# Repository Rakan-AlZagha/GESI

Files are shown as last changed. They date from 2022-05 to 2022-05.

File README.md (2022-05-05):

# Gesture-Enabled System Interaction (GESI) 

Wide

## Introduction
This project was created as part of the Department of Computer Science, Trinity College (Hartford, CT), Senior Capstone project. I was advised by Dr. Maminur Islam both semesters. 

You will find all files: training and testing scripts, 3D STL designs, presentation and poster, and the code for the ESP-EYE live stream here.

## Abstract
Gesture Enabled System Interaction (GESI) is a project that enables users to interact effectively
with devices based on intuitive hand gestures. 

With the exception of gaming, touch and voice have dominated the way we interact with technology over the last decade. Enabling users to utilize gestures to operate and interact with appliances, speakers, lights, machines, and more
will allow us to develop more interactive and robust technology. 

The purpose of this project is to add another dimension of user interaction with various systems and technologies. To achieve
this, I am developing a wearable piece of technology using the ESP-EYE microcontroller that will be mounted to a pair of 3D-designed and printed glasses. The microcontroller will broadcast raw real-time video of a user’s hand motions (first-person view) which will be intercepted by the object-detection algorithm running remotely. 

Once a gesture is recognized by the deep-learning object detection model, an API request will be sent to Amazon’s Alexa API (referred to as “skills”) for direct device interaction. A user will be able to interact with any device connected to
their Alexa account by issuing gestures that are unique to that specific device. 

As the project progresses, ultimately, the end-product will be optimized for reliable, robust, and natural
interactions with connected technologies.

## Current Work
Looking at current day approaches to gesture-based technology, the work is split between IoT developers and some commercial products. A company named Fibaro designs smart home devices/applications and has recently developed a gesture-based technology called “Swipe”. The idea behind it is to place a tablet in a common space at home and issue gestures to control home devices and music systems. The issue with this design is the lack of movability and robustness. Users need to be in a certain place in their house and within a certain range of proximity in order to operate these devices. It is not practical for user stories that would involve being able to operate devices via gestures from multiple locations. 

Other designs include hand-tracking via accelerometers, using a Xbox Kinect as a tracker, or using a wearable watch that records gestures. These designs are bulky, lack mobility, and do not directly address the need for gesture-control to be natural and robust. There is one project, named SHAIDES by Nick Bild, a software engineer, that begins to address the issues above. He utilizes one dynamic gesture to turn on and off a light using a bulky Jetson Nano and a Raspberry Pi Camera (later switches to a microcontroller for more lightweight use). He accomplishes interfacing with one API (Phillips REST), but this is the extent that his project went to and lacks integration to a broader range of devices and user autonomy over gestures. 

Taking all of this into consideration, I aim to follow the effective design choices of previous work and avoid previous mistakes that resulted in failures. This project will focus on usability, mobility (in terms of being able to utilize it from multiple locations), and integrating a user-friendly and natural interface. I will be taking the core ideas expressed by the aforementioned researchers and IoT projects and extending it to a unique model that incorporates the most effective hardware and software choices. My design will be unique to previous approaches by allowing for users to interface with multiple devices based on defined gestures (static/dynamic), integrate a lightweight sleek wearable solution, and cover a broad range of functionality (across types of devices). 

## Significance
With the emergence of platforms such as Amazon Alexa and Google Home that allow you to connect smart devices to one platform, the relevance of this project is vast. The best way to encapsulate the significance of this project is to provide a scenario. 

Imagine you, a proud owner of this product (GESI), are coming home from work and with the gesture of your hand you can open your car garage. Right when you enter the house, you decide to turn on the lights with another gesture. Say you are feeling cold on a cold fall evening, with one gesture you can control your thermostat without the click of a button. Music? Pre-programmable gestures to access your favorite playlists and automatically play on your bluetooth speaker via Alexa. Bedtime? One gesture to power off your room lights, close your motorized curtains, and turn off your TV with a specified night mode gesture-motion. The possibilities are simply endless. This product would enable users to access another dimension of user-interaction with systems. 

## Methodology 
### Diagram of technical process
final-diag

MediaPipe Hands is a high-fidelity hand and finger tracking solution. It employs machine learning (ML) to infer 21 3D landmarks of a hand from just a single frame. It is used here to extract the most important nodes on the palm and fingers to train the gesture-recognition algorithm and later test the unknown gestures coming from the user. 

VoiceMonkey allows you to trigger Alexa routines externally from services such as IFTTT and Home Assistant and offers dynamic text-to-speech (TTS) capabilities. Essentially, we can use Alexa without speaking. It is as simple as creating a "Monkey", creating an Alexa routine to pair the monkey with Alexa's functionality, and then triggering it from the testing script (pair gesture to command).

For more information regarding MediaPipe and VoiceMonkey:
https://google.github.io/mediapipe/solutions/hands.html

https://voicemonkey.io/

## Final Product
### Glasses



### Glasses with battery and ESP-EYE mounted
IMG_9500 (2)

### Smart Home Mode
https://user-images.githubusercontent.com/56772433/166870876-bbc511b6-0143-480e-b7a3-64f70b14b61e.mp4

https://user-images.githubusercontent.com/56772433/166870782-8f62e7c0-6f62-45b8-8c57-db330b099c72.mp4

### Presentation Mode

https://user-images.githubusercontent.com/56772433/166870836-4533b042-be06-4260-839d-aab758ede73c.mp4

### Music Mode

https://user-images.githubusercontent.com/56772433/166870812-0328952b-4d6f-45e7-8189-26ac06d0df64.mp4

## Special considerations
Learning: 
- OpenCV course (LinkedIn Learning)
- Object-detection course
- Microcontroller and Arduino course
- General IoT course
- MediaPipe
- VoiceMonkey

### Special Equipment: 
ESP Eye Microcontroller - 
https://www.amazon.com/Espressif-ESP-Eye-Camera-Digital-Microphone/dp/B07RD7BG8L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

Powerbank for remote power - 
https://www.amazon.com/Diymore-Battery-Shield-Raspberry-Arduino/dp/B0784FPF8J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

Batteries - 
https://www.18650batterystore.com/products/samsung-25r-18650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

CAD designed glasses for microcontroller (can use local library 3D printer for free)

Budget = ~$50

## Future Directions
- Improve gesture-recognition algorithm in different conditions
- Train on different hand sizes for more accurate predictions
- Develop a user-oriented method of pairing gestures to commands via a web or iOS application
- Expanding to different smart-home interfaces (Google Home & HomePod)
- Improve comfort of glasses and make design sleeker

### Please email alzagharakan@gmail.com with any questions, ideas, or comments.

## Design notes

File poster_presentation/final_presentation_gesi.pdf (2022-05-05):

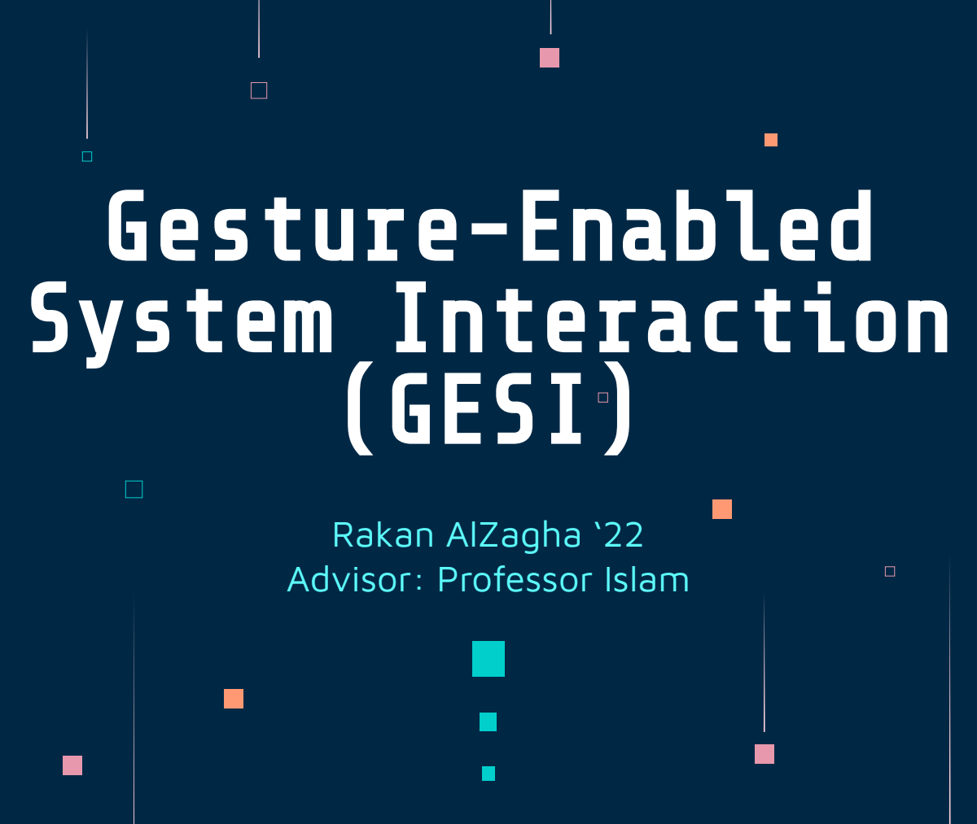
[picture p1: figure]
Rakan AlZagha ‘22 Advisor: Professor Islam; Gesture-Enabled System Interaction (GESI)

# Develop a user-friendly end product that allows users to interact effectively with devices based on intuitive hand

gestures.

# Project Goal

# Journey to Completion

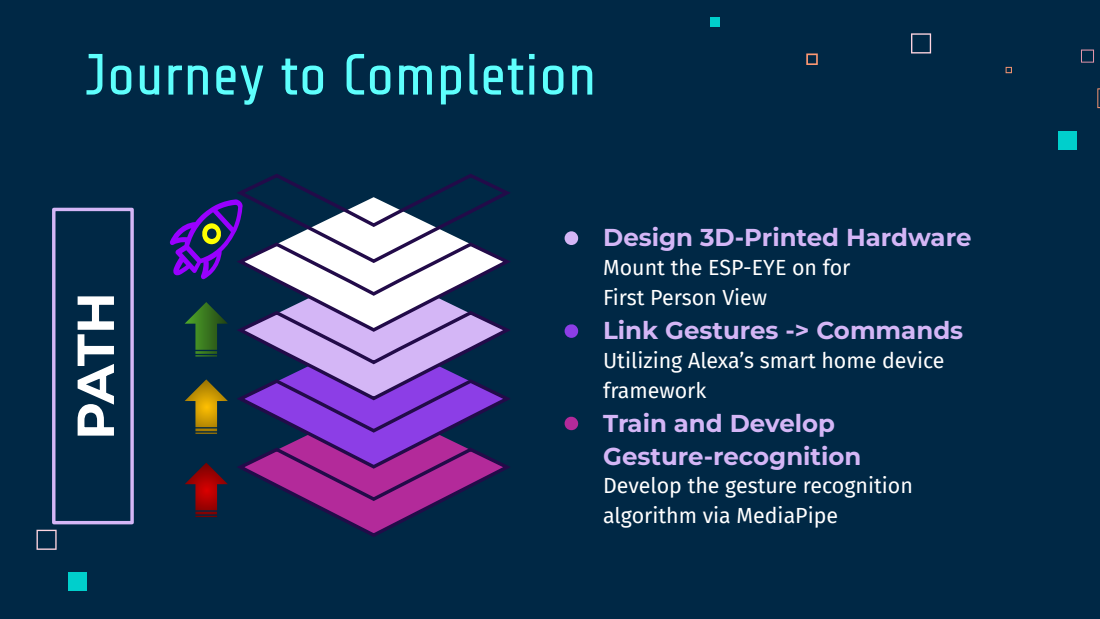
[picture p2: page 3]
PATH

Design 3D-Printed Hardware
Mount the ESP-EYE on for
First Person View
Link Gestures -> Commands
Utilizing Alexa’s smart home device
framework
Train and Develop
Gesture-recognition
Develop the gesture recognition
algorithm via MediaPipe

# Technical Specifications

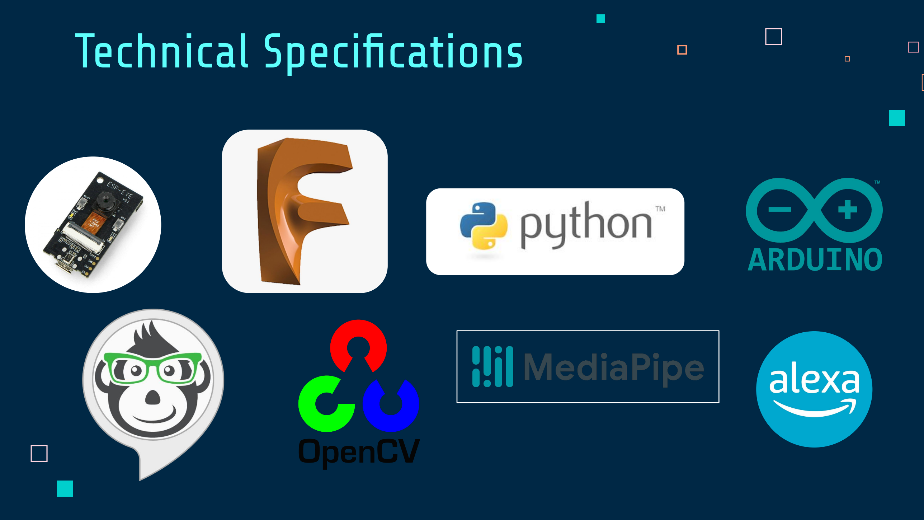
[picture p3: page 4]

# Hand-Tracking Solution

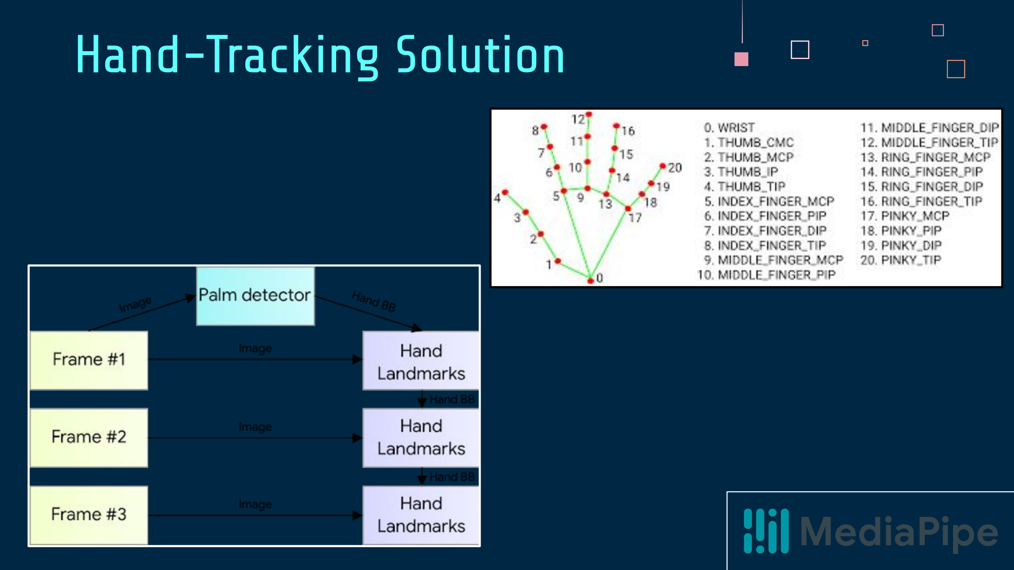
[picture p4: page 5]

# Technical Process

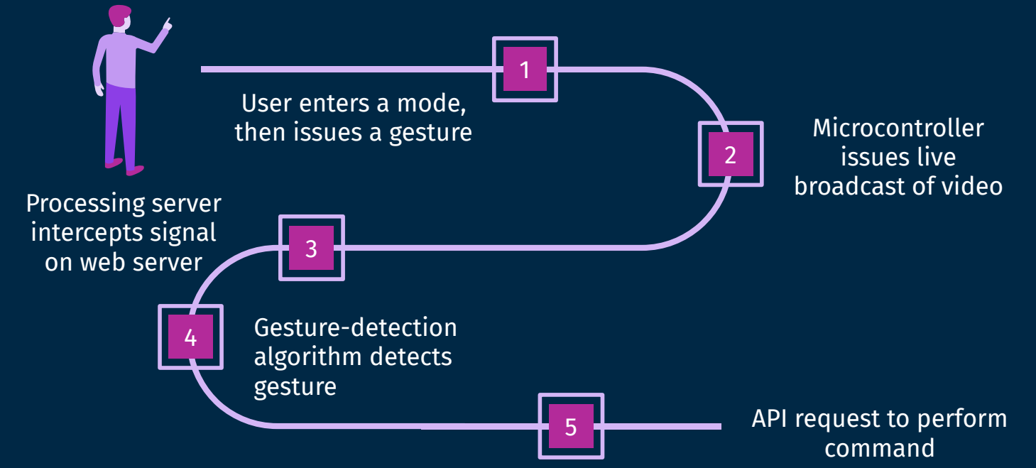
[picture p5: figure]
API request to perform; command; Processing server intercepts signal on web server; User enters a mode, then issues a gesture; Gesture-detection algorithm detects gesture; Microcontroller issues live broadcast of video

# 3D Prints

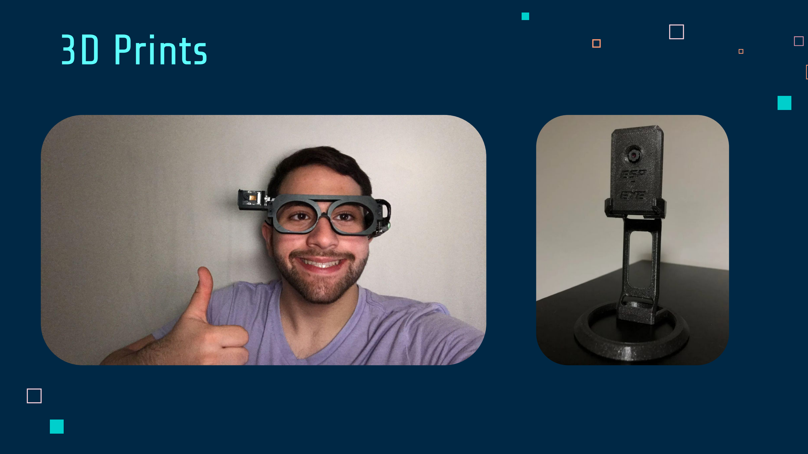
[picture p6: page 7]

# DEMO TIME

# Gesture Tracking

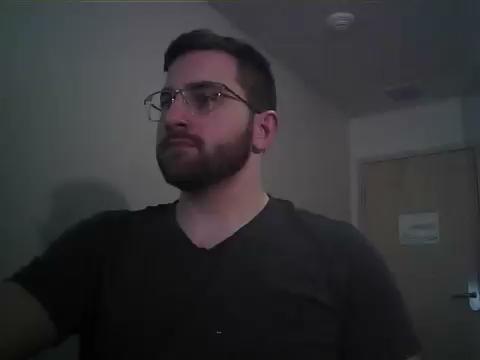
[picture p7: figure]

# Smart Home Mode

# Smart Home Mode

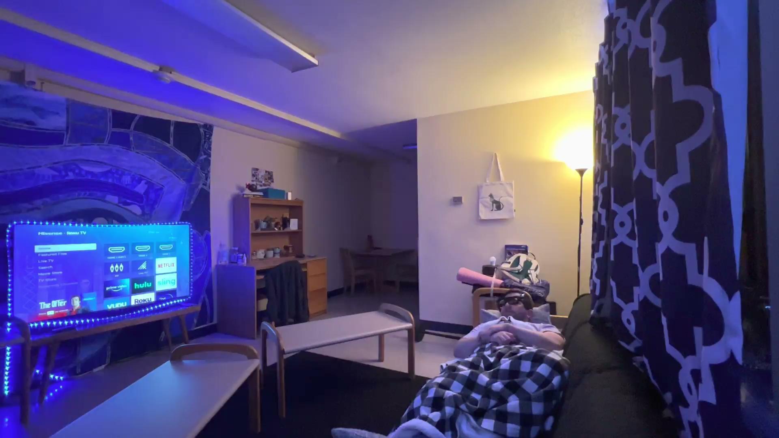
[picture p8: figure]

# Music Mode

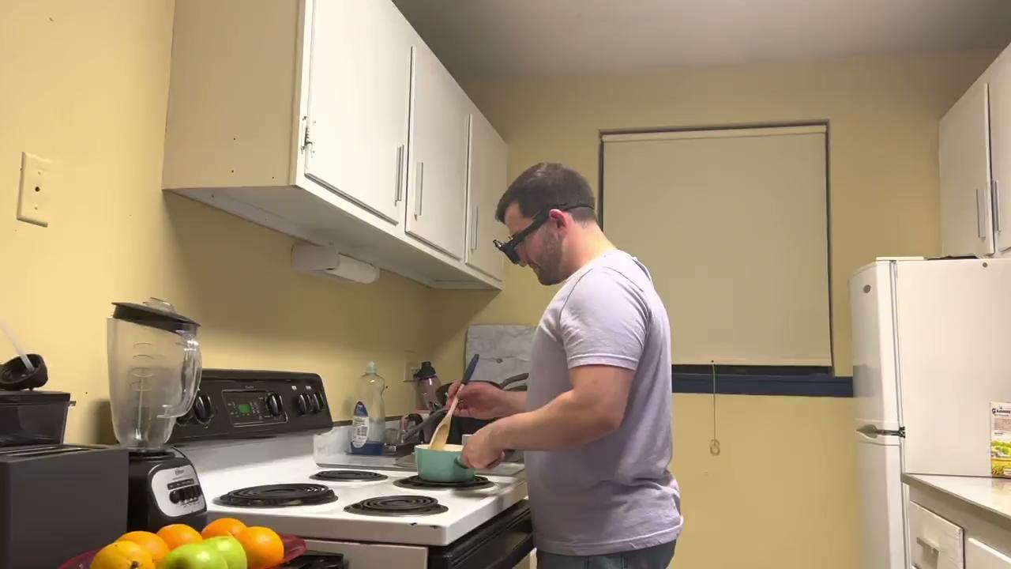
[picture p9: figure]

# Presentation Mode

# THANK YOU!

### Questions? Comments?

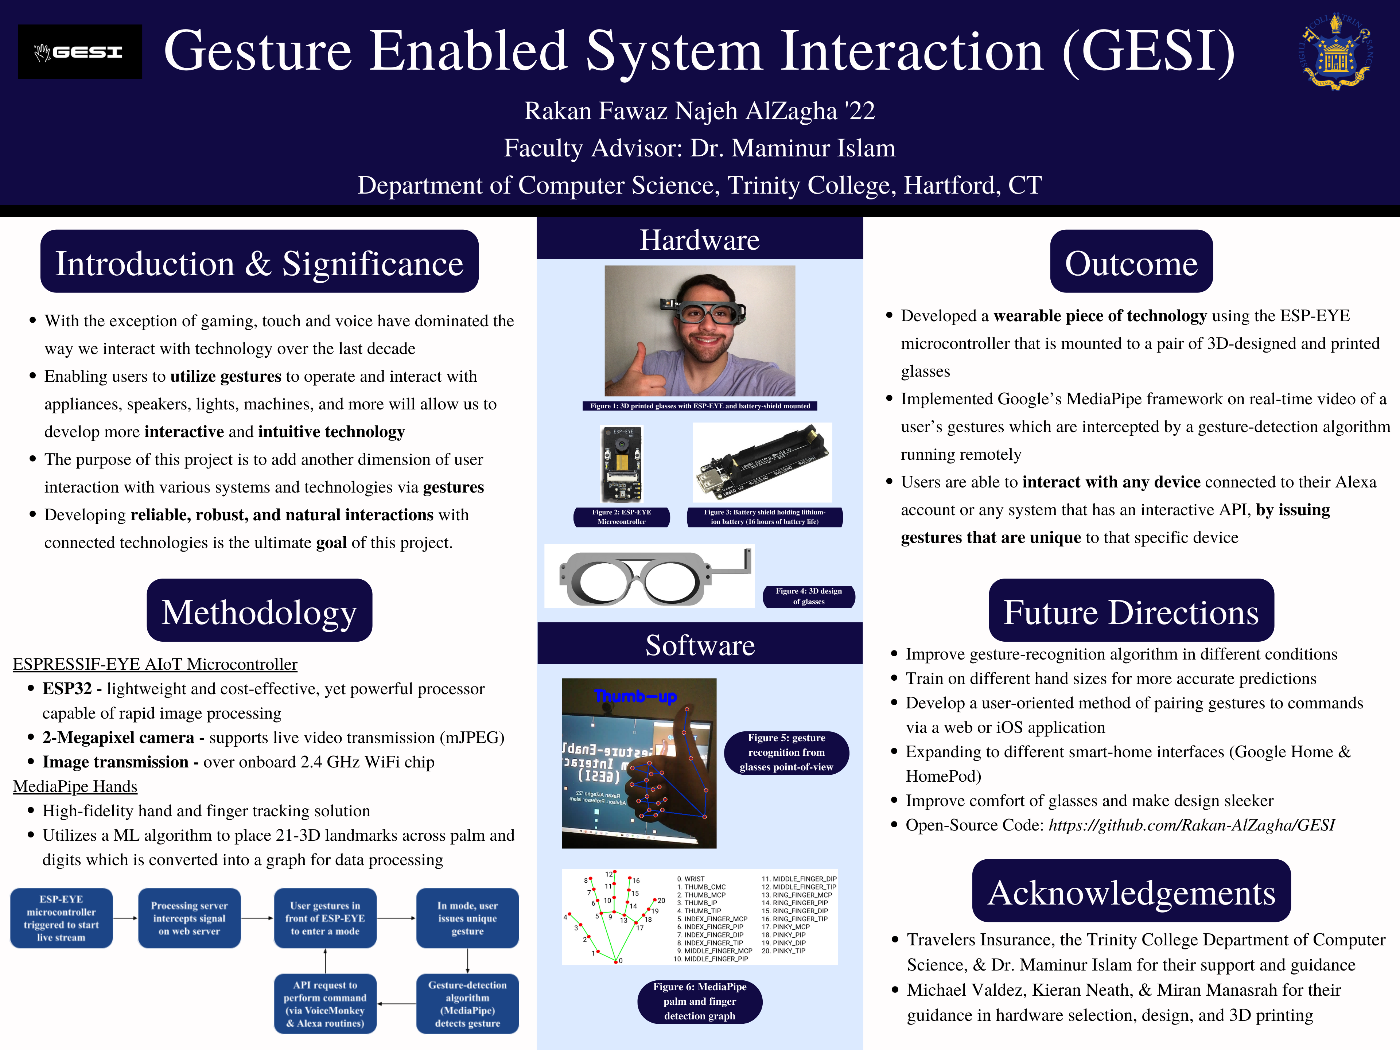
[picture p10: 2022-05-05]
poster_presentation/final_poster_GESI.png

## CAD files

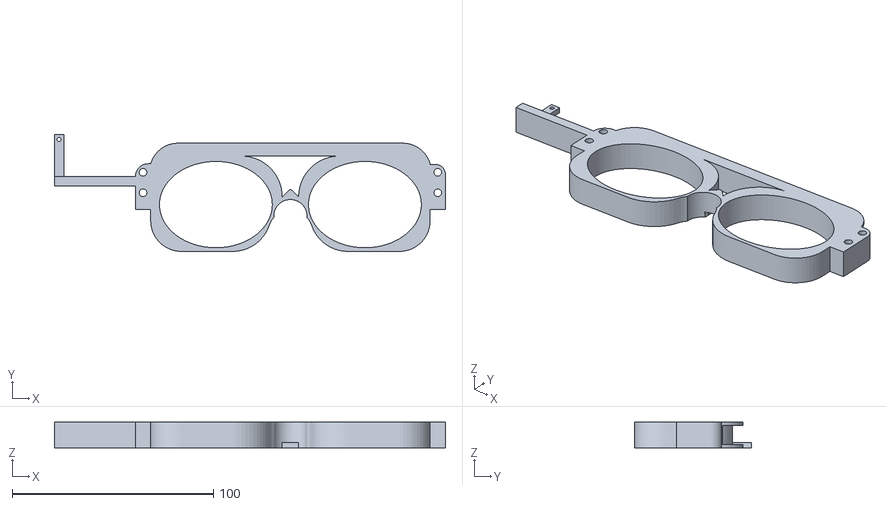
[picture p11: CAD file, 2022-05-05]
glasses_stl/final_glasses.stl
194.1 x 58.0 x 12.7

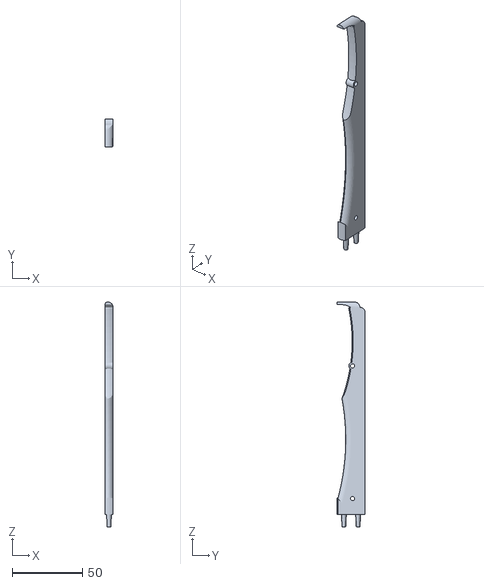
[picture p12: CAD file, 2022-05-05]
glasses_stl/final_legs.stl
5.91 x 20.3 x 160.7

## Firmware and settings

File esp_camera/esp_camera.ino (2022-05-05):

/*
 * File: Web Server Code
 * Date: 11/1/2021
 * Author: Rakan AlZagha & Arduino ESP32 Example Fragments
 * 
 * Purpose: Generate a web server with live stream
 */

#include "esp_camera.h"
#include "camera_pins.h"
#include "button_and_led_pins.h"
#include <WiFi.h>
#include "esp_timer.h"
#include "img_converters.h"
#include "Arduino.h"
#include "fb_gfx.h"
#include "soc/soc.h" //disable brownout problems
#include "soc/rtc_cntl_reg.h"  //disable brownout problems
#include "esp_http_server.h"
#include <ezButton.h>

#define PART_BOUNDARY "123456789000000000000987654321"

// network credentials
const char* ssid = "ESP32";
const char* password = "Raal2112!";

// create a new button on programmed pin #15
ezButton button(15);

// set the necessary details for the HTTP server API
static const char* _STREAM_CONTENT_TYPE = "multipart/x-mixed-replace;boundary=" PART_BOUNDARY;
static const char* _STREAM_BOUNDARY = "\r\n--" PART_BOUNDARY "\r\n";
static const char* _STREAM_PART = "Content-Type: image/jpeg\r\nContent-Length: %u\r\n\r\n";
httpd_handle_t stream_httpd = NULL;


// Set your Static IP address
IPAddress local_IP(192, 168, 137, 184);
// Set your Gateway IP address
IPAddress gateway(192, 168, 137, 1);
IPAddress subnet(255, 255, 0, 0);
IPAddress primaryDNS(8, 8, 8, 8); //optional
IPAddress secondaryDNS(8, 8, 4, 4); //optional

/*
 * Set up the web server and supporting components
 * 
 */
void setup() {
  serialSetup();
  camera_config_t config = cameraConfig(config);
  pinSetup();
  
  // initialize camera
  esp_err_t err = esp_camera_init(&config);
  sensor_t *s = cameraSensorConfig();

  // error-checking 
  if (err != ESP_OK) {
    Serial.printf("Camera init failed with error 0x%x", err);
    return;
  }
  // Wi-Fi connection
  wifiAndButtonSetup();
  serialPrint();

  // set debounce time to 50 milliseconds
  button.setDebounceTime(DEBOUNCE_TIME); 
}

/*
 * Provide start-up features for program
 * 
 */
 
void loop() {
  button.loop();
  // toggle white LED when function button is pressed
  if(button.isPressed()){
    digitalWrite(LED_BUILTIN, HIGH);
    startCameraServer();
  } 
  delay(1);
}

/*
 * Set up the serial debug output
 * 
 */
 
void serialSetup(){
  Serial.begin(115200);
  Serial.setDebugOutput(true);
  Serial.println();
}

/*
 * Set up the pin config for the ESP-EYE
 * 
 */
 
void pinSetup(){
  pinMode(13, INPUT_PULLUP);
  pinMode(14, INPUT_PULLUP);
  pinMode(LED_BUILTIN, OUTPUT);
  pinMode(LED_PIN, OUTPUT);
  pinMode(BUTTON_PIN, INPUT_PULLUP);
}

/*
 * Set up the WiFi and button start up
 * 
 */
 
void wifiAndButtonSetup(){
  // Wi-Fi connection
  if(!WiFi.config(local_IP, gateway, subnet, primaryDNS, secondaryDNS)) {
    Serial.println("STA Failed to configure");
  }
  WiFi.begin(ssid, password);
  while (WiFi.status() != WL_CONNECTED) {
    digitalWrite(LED_PIN, HIGH);
    Serial.print(".");
    delay(500);
  }
  digitalWrite(LED_PIN, LOW);  
}

/*
 * Serial monitor print messages
 * 
 */
 
void serialPrint(){
  Serial.println("");
  Serial.println("WiFi connected");
  Serial.print("Camera Stream Ready! Go to: http://");
  Serial.print(WiFi.localIP());
}

/*
 * Set up the stream handler for active camera stream
 * 
 * ADAPTED from ESP32 Documentation Examples
 * 
 */
 
static esp_err_t stream_handler(httpd_req_t *request){
  camera_fb_t * frame_buffer = NULL;
  esp_err_t response = ESP_OK;
  size_t _jpg_buf_len = 0;
  uint8_t * _jpg_buf = NULL;
  char * part_buf[64];

  // set http response type
  response = httpd_resp_set_type(request, _STREAM_CONTENT_TYPE);
  if(response != ESP_OK){
    return response;
  }

  while(true){
    // get frame by frame
    frame_buffer = esp_camera_fb_get();
    // no frames in buffer
    if (!frame_buffer) {
      Serial.println("Camera capture failed");
      response = ESP_FAIL;
    } 
    // frames captured
    else {
      if(frame_buffer->width > 400){
        if(frame_buffer->format != PIXFORMAT_JPEG){
          // convert frame to mJPEG
          bool jpeg_converted = frame2jpg(frame_buffer, 80, &_jpg_buf, &_jpg_buf_len);
          esp_camera_fb_return(frame_buffer);
          frame_buffer = NULL;
          if(!jpeg_converted){
            Serial.println("JPEG compression failed");
            response = ESP_FAIL;
          }
        } 
        else {
          _jpg_buf_len = frame_buffer->len;
          _jpg_buf = frame_buffer->buf;
        }
      }
    }
    //  send requests as reponses if ESP_OK
    if(response == ESP_OK){
      size_t hlen = snprintf((char *)part_buf, 64, _STREAM_PART, _jpg_buf_len);
      response = httpd_resp_send_chunk(request, (const char *)part_buf, hlen);
    }
    if(response == ESP_OK){
      response = httpd_resp_send_chunk(request, (const char *)_jpg_buf, _jpg_buf_len);
    }
    if(response == ESP_OK){
      response = httpd_resp_send_chunk(request, _STREAM_BOUNDARY, strlen(_STREAM_BOUNDARY));
    }
    if(frame_buffer){
      esp_camera_fb_return(frame_buffer);
      frame_buffer = NULL;
      _jpg_buf = NULL;
    } 
    else if(_jpg_buf){
      free(_jpg_buf);
      _jpg_buf = NULL;
    }
    if(response != ESP_OK){
      break;
    }
  }
  return response;
}

/*
 * Set up the the basics of the server to extract mJPEGs
 * 
 */
 
void startCameraServer(){
  httpd_config_t config = HTTPD_DEFAULT_CONFIG();
  config.server_port = 80;

  httpd_uri_t http_request = {
    .uri       = "/",
    .method    = HTTP_GET,
    .handler   = stream_handler,
    .user_ctx  = NULL
  };

  Serial.println("");
  Serial.printf("The web server is starting on default port: '%d'\n", config.server_port);
  if (httpd_start(&stream_httpd, &config) == ESP_OK) {
    httpd_register_uri_handler(stream_httpd, &http_request);
  }
  else{
    Serial.printf("The web server is failing to start on default port: '%d'\n", config.server_port);
  }
}

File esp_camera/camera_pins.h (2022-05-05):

#define PWDN_GPIO_NUM    -1
#define RESET_GPIO_NUM   -1
#define XCLK_GPIO_NUM    4
#define SIOD_GPIO_NUM    18
#define SIOC_GPIO_NUM    23
#define Y9_GPIO_NUM      36
#define Y8_GPIO_NUM      37
#define Y7_GPIO_NUM      38
#define Y6_GPIO_NUM      39
#define Y5_GPIO_NUM      35
#define Y4_GPIO_NUM      14
#define Y3_GPIO_NUM      13
#define Y2_GPIO_NUM      34
#define VSYNC_GPIO_NUM   5
#define HREF_GPIO_NUM    27
#define PCLK_GPIO_NUM    25

static camera_config_t cameraConfig(camera_config_t config){
  config.ledc_channel = LEDC_CHANNEL_0;
  config.ledc_timer = LEDC_TIMER_0;
  config.pin_d0 = Y2_GPIO_NUM;
  config.pin_d1 = Y3_GPIO_NUM;
  config.pin_d2 = Y4_GPIO_NUM;
  config.pin_d3 = Y5_GPIO_NUM;
  config.pin_d4 = Y6_GPIO_NUM;
  config.pin_d5 = Y7_GPIO_NUM;
  config.pin_d6 = Y8_GPIO_NUM;
  config.pin_d7 = Y9_GPIO_NUM;
  config.pin_xclk = XCLK_GPIO_NUM;
  config.pin_pclk = PCLK_GPIO_NUM;
  config.pin_vsync = VSYNC_GPIO_NUM;
  config.pin_href = HREF_GPIO_NUM;
  config.pin_sscb_sda = SIOD_GPIO_NUM;
  config.pin_sscb_scl = SIOC_GPIO_NUM;
  config.pin_pwdn = PWDN_GPIO_NUM;
  config.pin_reset = RESET_GPIO_NUM;
  config.xclk_freq_hz = 20000000;
  config.pixel_format = PIXFORMAT_JPEG;
  config.frame_size = FRAMESIZE_SVGA;
  config.jpeg_quality = 10;
  config.fb_count = 1;

  return config;
}

sensor_t * cameraSensorConfig(){
  sensor_t *s = esp_camera_sensor_get();
  s->set_vflip(s, 1);          // 0 = disable , 1 = enable
  s->set_contrast(s, 2);       // -2 to 2
  s->set_saturation(s, -2);     // -2 to 2

  return(s);
}

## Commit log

2022-05-05 commit message
    [final_data.csv, final_names.csv, gesture_data.csv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]
2022-05-05 stl files
    [final_glasses.stl, final_legs.stl]
2022-05-05 additional materials
